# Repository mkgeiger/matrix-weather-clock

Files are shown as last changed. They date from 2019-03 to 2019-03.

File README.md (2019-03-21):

# LED matrix clock with weather informations

## Overview

After my old 7-segmented clock in the living room gave up, I decided to build my own really fancy eye catching clock. The decicion fell on a LED matrix clock (after a Nixie clock was ruled out because of its limited capabilities and relative short tube lifes) because of its 80s retro look. The feature for my needs are:

* the device shall only communicate over WIFI to the outside world
* configurable WIFI access parameters
* the clock shall be using NTP to adjust its time automatically (I am always tired of setting the time after a power failure or when there is a change to the daylight saving time)
* the color of the time shall be configurable and also the seconds to be displayed or not
* a flashing colon (1/s) and a scrolling of the digits (from top to down) for the retro look
* displaying permanently the ouside temperature with a color gradient from blue (cold) to red (hot)
* displaying the actual weather icon and 2 weather forecast icons in the menu row, or alternativly the humidity or the air pressure
* changing the menu by pressing the push button shall have a retro scrolling effect
* the OpenWeatherMap API shall be used for requesting all weather information (I know its sometimes less accurate then commmercial ones, but its free!)
* all individual settings like time zone (incl. daylight saving and nornal time), OpenWeatherMap API key, OpenWeatherMap API city, OpenWeatherMap API units, NTP server address and motion detection hold time shall be configurable with a WEB server providing a settings page.
* a PIR (Pyroelectric Infrared Sensor) shall turn on the display when motion is detected and turn off the display again after a configurable time
* displaying popup notification messages from Android mobile phones

## Mechanics

The different layers
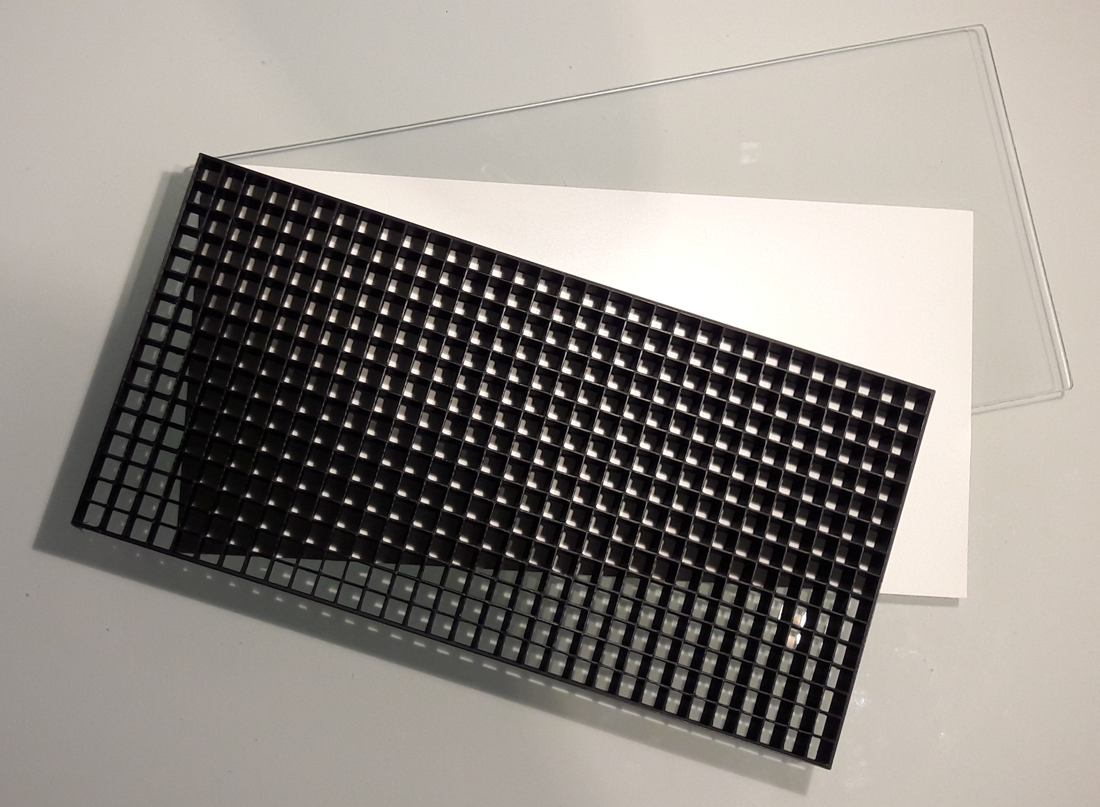
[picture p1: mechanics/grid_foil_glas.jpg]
Layers


### Dividing grid

You need a dividing grid in order to prevent neighbour pixels from blending colors. Without a dividing grid, there will be no sharp edges between two pixels, but a gradient, making the resulting image look blurry. The grid I designed is for a LED matrix display 32x16 RGB P6, means for 6mm led raster. The STL-file (an abbreviation of "stereolithography") created with FreeCad can be downloaded [here](/mechanics/grid.stl). The STL-file can be sent to any online 3D-Print service.

### Diffuser

It is very important to take the thinnest foil but with the most diffused effect at the same time. Don't take diffused acrylic glas, this is too thick and too blury. Plastic sheets from crafting suppliers are also most times too blury. Good results you get with adhesive foils for windows for privacy. I ordered my foils at [Velken](www.velken.de) (item no. 213010 or 213001). Glue instructions from Velken are included.

### Glas pane

Online offers for individual sizes of panes you get at Ebay. A 2mm thick pane is enough. The diffuser foil is glued onto the glas pane. 

## Hardware

### Display

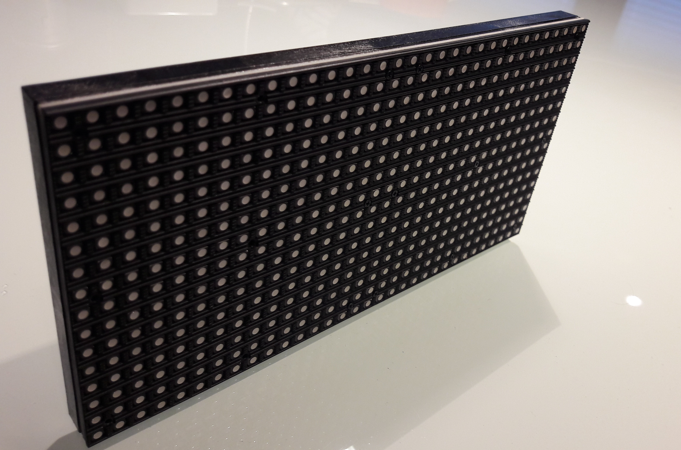
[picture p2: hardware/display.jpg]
Display


This is a LED matrix display which has in total 512 (32x16) RGB LEDs. If you want to learn more about the internal electronic details of such a display, please visit this page: https://bikerglen.com/projects/lighting/led-panel-1up/#The_LED_Panel. The setup and cabling for usage with the PxMatrix driver you should visit the page: https://github.com/2dom/PxMatrix/blob/master/README.md and https://learn.adafruit.com/32x16-32x32-rgb-led-matrix/new-wiring. For powering please visit this page: https://learn.adafruit.com/32x16-32x32-rgb-led-matrix/powering. The main power supply for the display should deliver at least a current of 2A. I had to power the display with about 4.3 Volt, maybe because the logic of display does not detect High-levels (3.3 Volt) from the ESP8266 correctly when powered with 5 Volt.

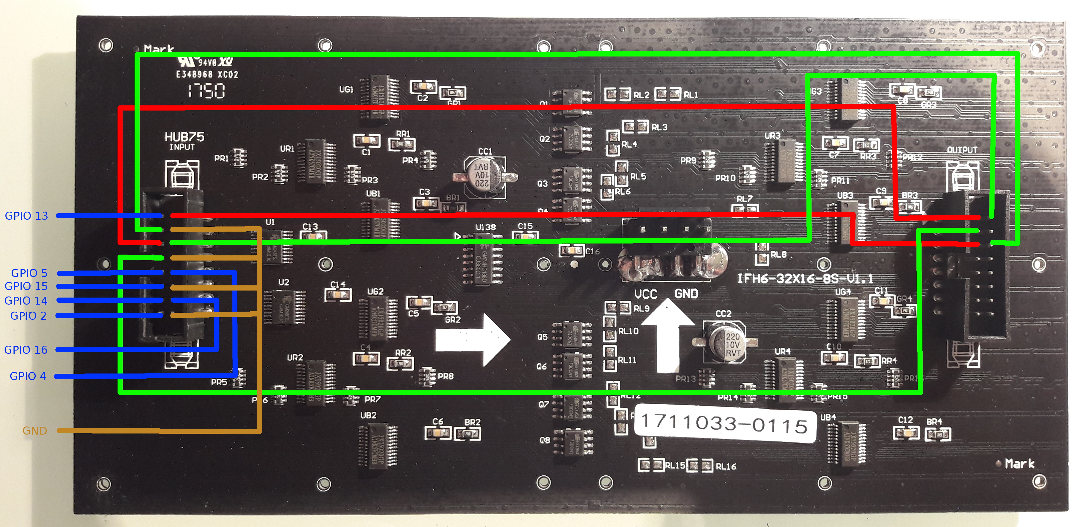
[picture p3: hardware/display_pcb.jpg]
Display


### NodeMcu ESP8266-12E

I decided to take this microcontroller board because of its power, easy programming, WIFI and small form factor. Following GPIOs are used:

  Signal    | ESP8266 | NodeMcu
  ----------|---------|--------
  MOSI (R0) | GPIO13  | D7
  A         | GPIO5   | D1
  B         | GPIO4   | D2
  C         | GPIO15  | D8
  CLK       | GPIO14  | D5
  OE        | GPIO2   | D4
  STB       | GPIO16  | D0
  PIR       | GPIO12  | D6
  BUTTON    | GPIO0   | D3
  GND       | GND     | GND
  
This module can be obtained at Ebay for about 3€.  
  
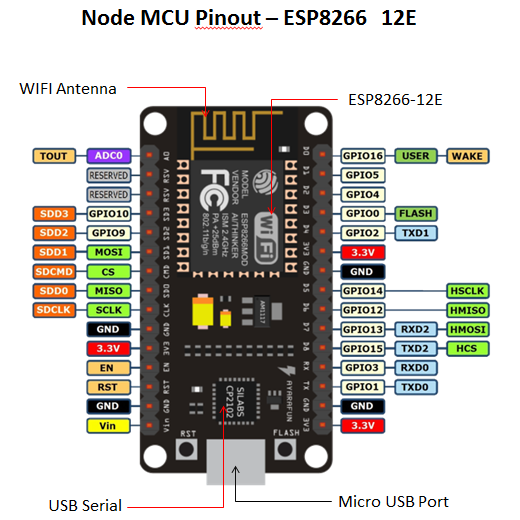
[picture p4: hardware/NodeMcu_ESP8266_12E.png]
NodeMcu
  

### PIR sensor

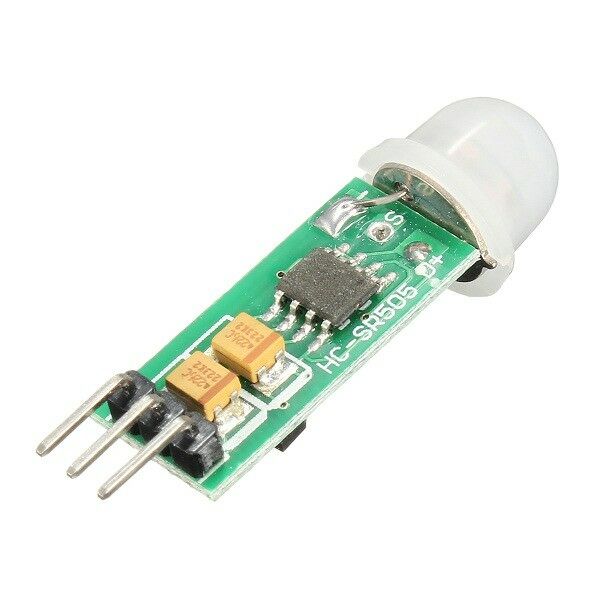
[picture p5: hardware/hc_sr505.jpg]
 

The PIR sensor is used to switch off the display after some configurable time (default 10 min), when no motion is detected. This is mainly for extending the lifetime of the display LEDs. I have choosen the embedded PIR sensor HC-SR505, which is one of the smallest and cheapest. I had to add a suppression choke to filter high frequency signals like WIFI from he power lines, otherwise I got false positives and the display never turned off. The sensing distance for me is also very poor (only 2m) and not 3m as in the datasheet. All in all I have deaktivated the "display switching off" in mean time (DISPLAY_ON_PERMANENTLY), until the problem with the distance is solved. 2 ways to solve: 1. increasing the amplifying factor of the HC-SR505 OPAMP or 2. using the radar sensor [RWCL-0516](/hardware/rwcl_0516.jpg). I tend to solution 2 but no idea of the permanent microwave emission influencing the healt.

## Software

### Preparations

First install the [Arduino IDE](https://www.arduino.cc/en/main/software). Under board administration install support for "NodeMCU 1.0 (ESP-12E Module)". The CPU frequency has to be configured for "160 MHz". Following libraries have to be installed:

* PxMatrix
* Time
* Timezone
* WiFi
* WiFiManager
* DNSServer
* ESP8266WebServer
* ESP8266HTTPClient
* ESP8266mDNS

### NTP client

The NTP client adjusts the internal clock every 10 minutes. The timestamp (UTC Unix time) is converted to the local timezone considering the standard or daylight saving time. An individual NTP server (default: de.pool.ntp.org) can be configured over the WEB interface.

### Time Zone

Timezone

The time zone can be configured over the WEB interface. If the daylight saving time is not applicable to your time zone set both standard and dylight saving times the same values.

### OpenWeatherMap API

* first request an account at [OpenWeatherMap](https://home.openweathermap.org/users/sign_up) to obtain an individual API key.
* test following URLs in your browser and fill in your city and API key: [query1](http://api.openweathermap.org/data/2.5/weather?q=<city>&appid=<apikey>&units=metric) and [query2](http://api.openweathermap.org/data/2.5/forecast?q=<city>&appid=<apikey>&units=metric&cnt=2)
* when you get back the weather information in JSON format, everything is ok. You can now enter the API key, city and unit in the WEB interface.

The [weather condition codes](/datasheets/IconsOpenWeatherMap.pdf) (more detailed than the weather icons) are determined from the JSON response and the corresponding icons (which are designed by myself especially for a matrix display) are displayed. Most icons exist for day and night. A binary search is applied to the icon array when selecting one icon. The [cJSON project](https://github.com/DaveGamble/cJSON) source code is used for parsing the JSON response.

### Motion detection

The status of the PIR sensor is read cyclic. Immediately when a motion is detected the display shows all graphics. The hold time (when no motion is detected anymore) until the display is drawn completely black can be configured in the WEB interface (default: 10 min). Because the range is very poor an alternative would be to use a short range radar for motion detection. Until this is not completely clarified the timeout of the hold time is disabled in the source code to leave the display permanently on.

### HTTP server

The WEB interface is used to store the settings of OpenWeatherMap API, NTP server, time zone and motion detection hold time in the EEPROM. The assigned IP can be found in the router settings. The WIFI settings can be resetted with http://IPaddress/resetWifi. Due to implemented multicast DNS (mDNS) the WEB interface can also be accessed via http://MatrixWeatherClock.local instead of giving the IP. When the "Reset WIFI" button was pressed an access point is started with the following reset (SSID: matrix_weather_clock IP: 192.168.1.1) and new WIFI settings can be configured.

### Android popup notification messages

If desired the user allows Android mobile phones to display popup notification messages like from E-Mail, Whatsapp, Messenger, etc. For this purpose a small App called [LinConnect Client](https://apkpure.com/linconnect-for-linux/com.willhauck.linconnectclient) has to be installed on the Android mobile phone. The LinConnect Client implements the Bonjour-protocol to discover automatically devices in the network offering the (LinConnect-) service. The MatrixWeatherClock acts as a mDNS-responder offering a service for LinLonnect, over which text messages can be transmitted from the client (Android phone) to the server (MatrixWeatherClock). This is done by sending a HTTP PUSH-request, which contains in its HTTP-header the base64-encoded notification-header and -information. The LinConnect Client can be configured which Apps are allowed to send notification messages. The message pops up in the menue line and scrolls from the right to the left.

### Drawing

The display refresh cycle for the [PxMatrix](https://github.com/2dom/PxMatrix) library is configured to 2 ms. The drawing cycle is configured to 100 ms. Within these 100 ms all graphical elements are drawn. A temporary buffer of 1kbyte (32 columns x 16 rows x 2 bytes color) is used as a double buffer, to which every graphical element can draw in its draw cycle. At the end of the draw cycle the complete buffer is copied to the PxMatrix interface to control the LEDs. At the beginning of each draw cycle the buffer is completely cleared. All graphical text elements can be drawn with an individual color. The 100 ms cycle time has been choosen because of the animation effects like colon blinking, digit-, menue- and popup-notification-message scrolling. Menue scrolling is triggered by a push button event.

## Photos

Actual weather icon and weather forecast icons (default view)
(the PIR sensor is visible in the upper left corner, the push button at the upper side of the wooden frame is not visible)

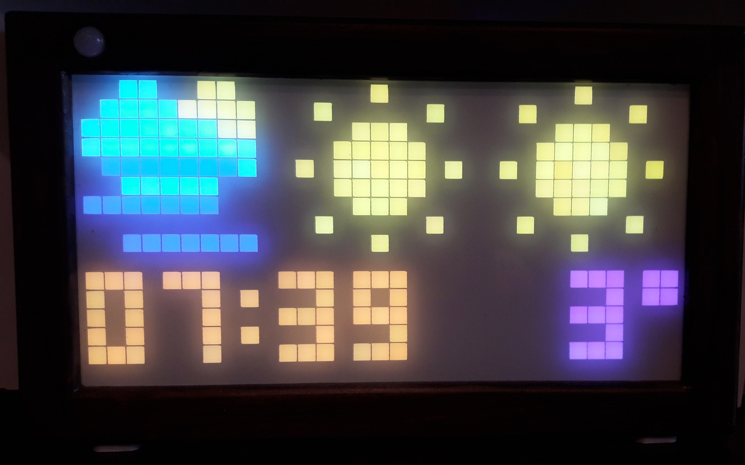
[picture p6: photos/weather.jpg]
Weather


Humidity view (visible after the 1st press of the push button)

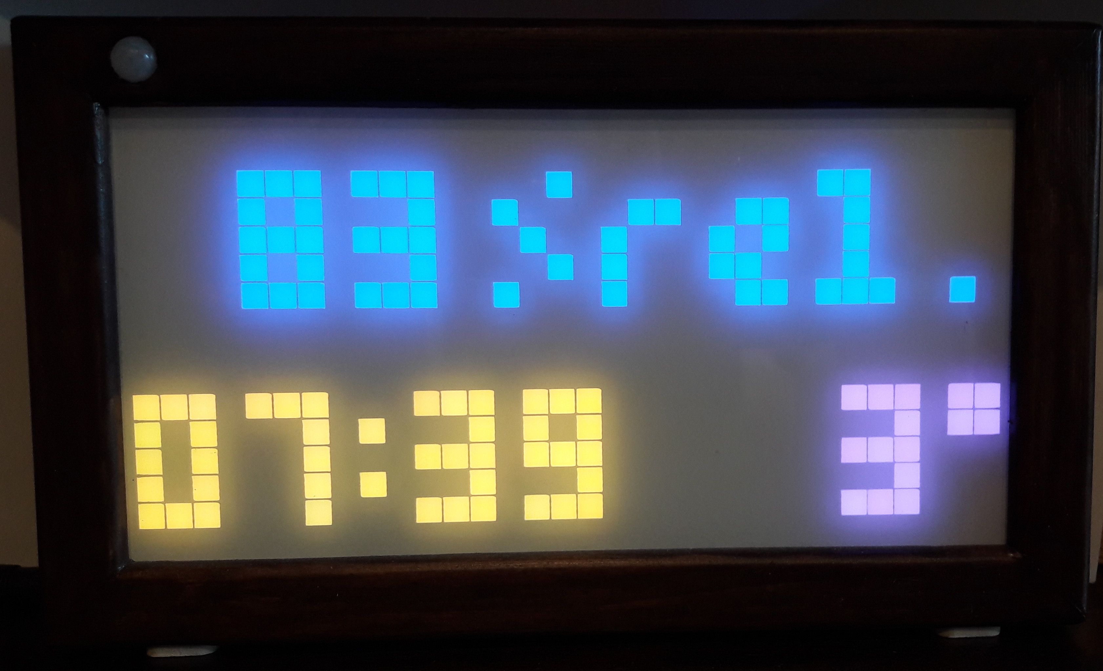
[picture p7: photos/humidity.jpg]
Humidity


Air pressure view (visible after the 2nd press of the push button)

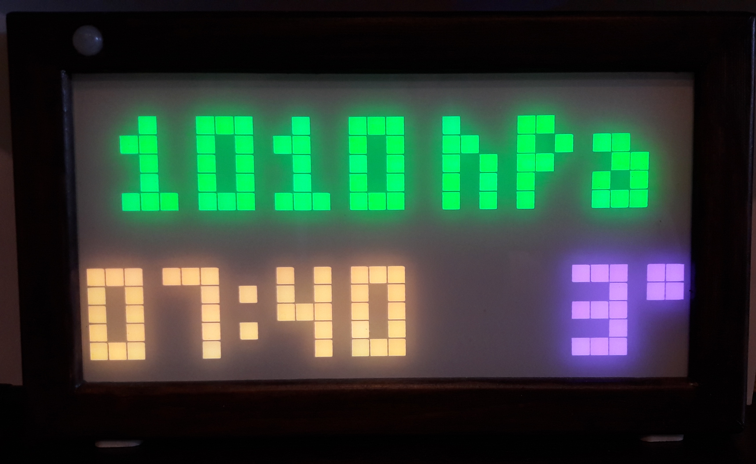
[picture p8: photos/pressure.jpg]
Pressure


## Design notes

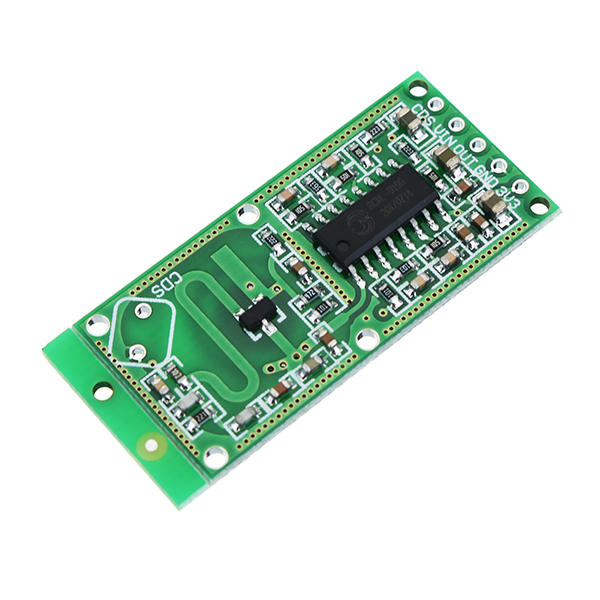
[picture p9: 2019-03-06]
hardware/rwcl_0516.jpg

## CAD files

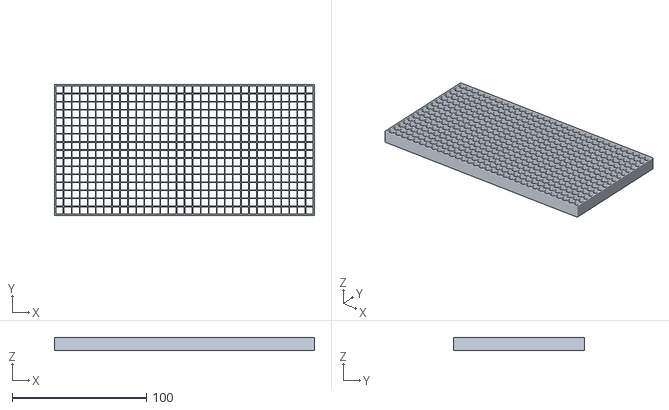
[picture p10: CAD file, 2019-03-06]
mechanics/grid.stl
193.5 x 97.5 x 10.0

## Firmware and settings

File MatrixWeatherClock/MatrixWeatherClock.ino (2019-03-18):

/*=============================================================================
 =======                            INCLUDES                            =======
 =============================================================================*/
#include <PxMatrix.h>
#include <Ticker.h>
#include <TimeLib.h>
#include <Timezone.h> 
#include <ESP8266WiFi.h>
#include <WiFiClient.h>
#include <ESP8266mDNS.h>
#include <DNSServer.h>          // Local DNS Server used for redirecting all requests to the configuration portal
#include <ESP8266WebServer.h>   // Local WebServer used to serve the configuration portal
#include <ESP8266HTTPClient.h>  // HTTPClient for web requests
#include <WiFiManager.h>        // WiFi Configuration Magic
#include <WiFiUdp.h>
#include <EEPROM.h>
#include "base64.h"
#include "cJSON.h"
#include "icons.h"
#include "font.h"

/*=============================================================================
 =======               DEFINES & MACROS FOR GENERAL PURPOSE             =======
 =============================================================================*/
// #define for Uart debugging (printf)
#undef DEBUG

// #undef when PIR range problem is solved
#define DISPLAY_ON_PERMANENTLY

// clock appearance
#undef CLOCK_DISPLAY_SECONDS

// rounding float to integer
#define ROUND_INT(d) ((int) ((d) + ((d) > 0 ? 0.5 : -0.5)))

// access point
#define AP_NAME "matrix_weather_clock"
#define AP_TIMEOUT 300

// general purpose
#define DISPLAY_WIDTH          32
#define DISPLAY_HEIGHT         16
#define NBR_DIGITS             10
#define UPDATE_PERIOD        6000
#define NTP_PACKET_SIZE        48
#define SEVENTYYEARS   2208988800UL
#define PIR_TIME_MAX         6000
#define NBR_MENUS               3
#define LINE0_END               9
#define WEBPAGE_BUFFER_SIZE  3500
#define WEEK_SELECTIONS         5
#define DOW_SELECTIONS          7
#define MONTH_SELECTIONS       12
#define LINE0_TEXT_HOLD_TIME   30   // 3 seconds
#define LINE0_TEXT_BUFSIZE    256

// EEPROM
#define OWM_API_KEY_OFFSET         0
#define OWM_API_KEY_LEN           32
#define OWM_CITY_OFFSET           32
#define OWM_CITY_LEN              32
#define OWM_UNITS_OFFSET          64
#define OWM_UNITS_LEN              8
#define NTP_SERVER_OFFSET         72
#define NTP_SERVER_LEN            32     
#define DT_WEEK_OFFSET           104  
#define DT_WEEK_LEN                1
#define DT_DOW_OFFSET            105
#define DT_DOW_LEN                 1
#define DT_MONTH_OFFSET          106
#define DT_MONTH_LEN               1
#define DT_HOUR_OFFSET           107
#define DT_HOUR_LEN                1
#define DT_OFFSET_OFFSET         108
#define DT_OFFSET_LEN              4
#define ST_WEEK_OFFSET           112  
#define ST_WEEK_LEN                1
#define ST_DOW_OFFSET            113
#define ST_DOW_LEN                 1
#define ST_MONTH_OFFSET          114
#define ST_MONTH_LEN               1
#define ST_HOUR_OFFSET           115
#define ST_HOUR_LEN                1
#define ST_OFFSET_OFFSET         116
#define ST_OFFSET_LEN              4
#define PIR_TIME_OFFSET          120
#define PIR_TIME_LEN               2

// used colors
#define RGB(r, g, b) ((((uint16_t)r & 0x00F8) << 8) | (((uint16_t)g & 0x00FC) << 3) | ((uint16_t)b >> 3))
#define BLK RGB(0, 0, 0)        // Black
#define CYN RGB(127, 255, 255)  // Light Cyan
#define GRY RGB(24, 24, 24)     // Dark Grey
#define YEL RGB(255, 255, 0)    // Yellow
#define BLU RGB(0, 0, 255)      // Blue
#define RED RGB(255, 0, 0)      // Red
#define GRN RGB(0, 255, 0)      // Green
#define ORG RGB(255, 127, 0)    // Orange
#define WHT RGB(255, 255, 255)  // White

// Port Pins for LED Matrix @ ESP8266
#define P_LAT 16
#define P_A    5
#define P_B    4
#define P_C   15
//#define P_D   12
//#define P_E    0
#define P_OE   2

/*=============================================================================
 =======                       CONSTANTS  &  TYPES                      =======
 =============================================================================*/
typedef struct
{
	uint8_t digit_old;
	uint8_t digit_new;
	uint8_t digit_show_old;
	uint8_t digit_show_new;
	uint8_t digit_anim_step;
	uint8_t digit_xoffset;
} digit_anim_t;

const uint16_t color_lut[] = {
		BLK,  // 0
		WHT,  // 1
		YEL,  // 2
		BLU,  // 3
		CYN,  // 4
		GRY,  // 5
		RED   // 6
};

/*=============================================================================
 =======                VARIABLES & MESSAGES & RESSOURCEN               =======
 =============================================================================*/
// timezone: Central European Time (Frankfurt, Paris)
TimeChangeRule daylight_time = { "DT", Last, Sun, Mar, 2, 120 };      //e.g. Central European Summer Time (CEST)
TimeChangeRule standard_time = { "ST", Last, Sun, Oct, 3, 60 };       //e.g. Central European Time (CET)
Timezone time_zone(daylight_time, standard_time);
TimeChangeRule *tcr;                                          //pointer to the time change rule, use to get the TZ abbrev

// Open Weather Map API
String owm_api_key;                                           // Open Weather Map API Key
String owm_city;                                              // Open Weather Map City
String owm_units;                                             // Open Weather Map Units, can be "imperial" or "metric"

// state machine
unsigned char state = 0;
boolean show_valid = false;

// to be displayed values
int temperature   = 9999;
int pressure      = 9999;
int humidity      = 9999;
char daynight_now = 'd';
char daynight_nxt[2] = {'d', 'd'};
int icon_id_now   = 0;
int icon_id_nxt[2] = {0};

// wifi stuff
WiFiManager wifiManager;
WiFiUDP udp;

// time.nist.gov NTP server address, port to listen and packet buffer
IPAddress timeServerIP; 
String ntp_server;          // e.g. de.pool.ntp.org
unsigned int localPort = 2390;
byte packetBuffer[NTP_PACKET_SIZE];

// Set web server port number to 80
ESP8266WebServer server(80);

// Set Linconnect server port number to 9090
WiFiServer linconnect_server(9090);

// matrix display definition, temporary display buffer and icon double buffers
PxMATRIX display(32,16, P_LAT, P_OE, P_A, P_B, P_C);
uint16_t display_buffer[DISPLAY_HEIGHT][DISPLAY_WIDTH] = {{BLK}};
uint8_t icon_buffer[3][2][ICON_HEIGHT * ICON_WIDTH];
uint8_t *icon_buffer_rd[3] = {icon_buffer[0][0], icon_buffer[1][0], icon_buffer[2][0]};
uint8_t *icon_buffer_wr[3] = {icon_buffer[0][1], icon_buffer[1][1], icon_buffer[2][1]};

// timer interrupts
Ticker display_ticker;
Ticker draw_ticker;
uint32_t ms100counter = 0ul;

// PIR
int pir_value = 0;
uint16_t pir_time;
uint16_t pir_count;

// Button
int button_value = 0;
uint8_t button_pressed = 0;

// Menu
uint8_t anim_line0_count = 0;
uint8_t menu = 0;
int16_t line0_xpos = 0;
boolean line0_process = false;
uint8_t line0_pre_showtime = 0;
uint8_t line0_post_showtime = 0;
char b64_decoded[LINE0_TEXT_BUFSIZE];

// Webpage
char webpage_buffer[WEBPAGE_BUFFER_SIZE];
String dt_week_selected[WEEK_SELECTIONS] = {"", "", "", "", ""};
String dt_dow_selected[DOW_SELECTIONS] = {"", "", "", "", "", "", ""};
String dt_month_selected[MONTH_SELECTIONS] = {"", "", "", "", "", "", "", "", "", "", "", ""};
String st_week_selected[WEEK_SELECTIONS] = {"", "", "", "", ""};
String st_dow_selected[DOW_SELECTIONS] = {"", "", "", "", "", "", ""};
String st_month_selected[MONTH_SELECTIONS] = {"", "", "", "", "", "", "", "", "", "", "", ""};
uint8_t dt_hour;
int     dt_offset;
uint8_t st_hour;
int     st_offset;

/*=============================================================================
 =======                              METHODS                           =======
 =============================================================================*/
const uint8_t * getIcon(char daynight, int icon_number)
{
	int left, middle, right, icon_nr;

	left = 0;
	right = NBR_ICONS - 1;

	while (left <= right)
	{
		middle = (left + right) / 2;

		icon_nr = (int)pgm_read_dword (&icon_list[middle].icon_number);

		if (icon_number > icon_nr)
		{
			left = middle + 1;
		}

		if (icon_number < icon_nr)
		{
			right = middle - 1;
		}

		if(icon_number == icon_nr)
		{
			if (daynight == 'd')
			{
				return (const uint8_t *)pgm_read_dword (&icon_list[middle].icon_day);
			}
			else
			{
				return (const uint8_t *)pgm_read_dword (&icon_list[middle].icon_night);
			}
		}
	}
	return NULL;
}

void draw_digit(uint8_t x_pos, uint8_t y_pos, uint8_t d, uint16_t color)
{
	uint8_t x, y;

	for (y = 1; y < (FONT_HEIGHT - 1); y ++)
	{
		for (x = 0; x < FONT_WIDTH; x ++)
		{
			display_buffer[y_pos + y - 1][x_pos + x] = color_lut[charactermap['0' + d][y][x]] & color;
		}
	}  
}

void draw_character(int16_t x_pos, int16_t y_pos, char c, uint16_t color)
{
	int16_t x, y;

	if ((x_pos > -3) && (x_pos < DISPLAY_WIDTH))
	{
		for (x = 0; x < FONT_WIDTH; x ++)
		{
			if ((y_pos > -3) && (y_pos < DISPLAY_HEIGHT))
			{
				for (y = 1; y < FONT_HEIGHT; y ++)
				{
					if (((x_pos + x) >= 0) && ((x_pos + x) < DISPLAY_WIDTH))
					{
						display_buffer[y_pos + y - 1][x_pos + x] = color_lut[charactermap[c][y][x]] & color;
					}
				}
			}
		}
	}
}

void draw_character_ext(int16_t x_pos, int16_t y_pos, const uint8_t character[][FONT_WIDTH], uint16_t color)
{
	int16_t x, y;

	if ((x_pos > -3) && (x_pos < DISPLAY_WIDTH))
	{
		for (x = 0; x < FONT_WIDTH; x ++)
		{
			if ((y_pos > -3) && (y_pos < DISPLAY_HEIGHT))
			{
				for (y = 1; y < FONT_HEIGHT; y ++)
				{
					if (((x_pos + x) >= 0) && ((x_pos + x) < DISPLAY_WIDTH))
					{
						display_buffer[y_pos + y - 1][x_pos + x] = color_lut[character[y][x]] & color;
					}
				}
			}
		}
	}
}

void utf8_draw_string(int16_t x_pos, int16_t y_pos, char *str, uint16_t color)
{
	int c[4];
	int i, len = 0;
	unsigned long code;

	for (i = 0; i < strlen(str); i ++)
	{
		c[0] = (unsigned char)str[i];
		if ((c[0] >= 0) && (c[0] <= 127))
		{
			draw_character (x_pos + len * (FONT_WIDTH + 1), y_pos, (char)c[0], color);
		}
		else if ((c[0] & 0xE0) == 0xC0)
		{
			c[1] = (unsigned char)str[i + 1];
			code = (((unsigned long)c[0]) << 8) | ((unsigned long)c[1]);
			switch(code)
			{
			case 0xC2A3:
				draw_character_ext(x_pos + len * (FONT_WIDTH + 1), y_pos, char_0xC2A3, color);
				break;
			case 0xC2A7:
				draw_character_ext(x_pos + len * (FONT_WIDTH + 1), y_pos, char_0xC2A7, color);
				break;
			case 0xC2A9:
				draw_character_ext(x_pos + len * (FONT_WIDTH + 1), y_pos, char_0xC2A9, color);
				break;
			case 0xC2AB:
				draw_character_ext(x_pos + len * (FONT_WIDTH + 1), y_pos, char_0xC2AB, color);
				break;
			case 0xC2B0:
				draw_character_ext(x_pos + len * (FONT_WIDTH + 1), y_pos, char_0xC2B0, color);
				break;
			case 0xC2B1:
				draw_character_ext(x_pos + len * (FONT_WIDTH + 1), y_pos, char_0xC2B1, color);
				break;
			case 0xC2B2:
				draw_character_ext(x_pos + len * (FONT_WIDTH + 1), y_pos, char_0xC2B2, color);
				break;
			case 0xC2B3:
				draw_character_ext(x_pos + len * (FONT_WIDTH + 1), y_pos, char_0xC2B3, color);
				break;
			case 0xC2B4:
				draw_character_ext(x_pos + len * (FONT_WIDTH + 1), y_pos, char_0xC2B4, color);
				break;
			case 0xC2B5:
				draw_character_ext(x_pos + len * (FONT_WIDTH + 1), y_pos, char_0xC2B5, color);
				break;
			case 0xC2BB:
				draw_character_ext(x_pos + len * (FONT_WIDTH + 1), y_pos, char_0xC2BB, color);
				break;
			case 0xC384:
				draw_character_ext(x_pos + len * (FONT_WIDTH + 1), y_pos, char_0xC384, color);
				break;
			case 0xC396:
				draw_character_ext(x_pos + len * (FONT_WIDTH + 1), y_pos, char_0xC396, color);
				break;
			case 0xC397:
				draw_character_ext(x_pos + len * (FONT_WIDTH + 1), y_pos, char_0xC397, color);
				break;
			case 0xC39C:
				draw_character_ext(x_pos + len * (FONT_WIDTH + 1), y_pos, char_0xC39C, color);
				break;
			case 0xC39F:
				draw_character_ext(x_pos + len * (FONT_WIDTH + 1), y_pos, char_0xC39F, color);
				break;
			case 0xC3A4:
				draw_character_ext(x_pos + len * (FONT_WIDTH + 1), y_pos, char_0xC3A4, color);
				break;
			case 0xC3B6:
				draw_character_ext(x_pos + len * (FONT_WIDTH + 1), y_pos, char_0xC3B6, color);
				break;
			case 0xC3B7:
				draw_character_ext(x_pos + len * (FONT_WIDTH + 1), y_pos, char_0xC3B7, color);
				break;
			case 0xC3BC:
				draw_character_ext(x_pos + len * (FONT_WIDTH + 1), y_pos, char_0xC3BC, color);
				break;
			default:
				draw_character_ext(x_pos + len * (FONT_WIDTH + 1), y_pos, char_unknown, color);
				break;
			}
			i += 1;
		}
		else if ((c[0] & 0xF0) == 0xE0)
		{
			c[1] = (unsigned char)str[i + 1];
			c[2] = (unsigned char)str[i + 2];
			code = (((unsigned long)c[0]) << 16) | (((unsigned long)c[1]) << 8) | ((unsigned long)c[2]);
			switch(code)
			{
			case 0xE2809C:
				draw_character_ext(x_pos + len * (FONT_WIDTH + 1), y_pos, char_0xE2809C, color);
				break;
			case 0xE2809E:
				draw_character_ext(x_pos + len * (FONT_WIDTH + 1), y_pos, char_0xE2809E, color);
				break;
			case 0xE282AC:
				draw_character_ext(x_pos + len * (FONT_WIDTH + 1), y_pos, char_0xE282AC, color);
				break;
			default:
				draw_character_ext(x_pos + len * (FONT_WIDTH + 1), y_pos, char_unknown, color);
				break;
			}
			i += 2;
		}
		else if ((c[0] & 0xF8) == 0xF0)
		{
			c[1] = (unsigned char)str[i + 1];
			c[2] = (unsigned char)str[i + 2];
			c[3] = (unsigned char)str[i + 3];
			code = (((unsigned long)c[0]) << 24) | (((unsigned long)c[1]) << 16) | (((unsigned long)c[2]) << 8) | ((unsigned long)c[3]);

			if (((code >= 0xf09f9880) && (code <= 0xf09f988f)) ||
					((code >= 0xf09f9897) && (code <= 0xf09f989d)) ||
					((code >= 0xf09f9982) && (code <= 0xf09f9983)))
			{
				draw_character_ext(x_pos + len * (FONT_WIDTH + 1), y_pos, char_smile, WHT);
			}
			else if (((code >= 0xf09f9890) && (code <= 0xf09f9891)) ||
					((code >= 0xf09f98b6) && (code <= 0xf09f98b7)) ||
					(code == 0xf09f9984))
			{
				draw_character_ext(x_pos + len * (FONT_WIDTH + 1), y_pos, char_neutral, WHT);
			}
			else if (((code >= 0xf09f9892) && (code <= 0xf09f9896)) ||
					((code >= 0xf09f989e) && (code <= 0xf09f98b5)) ||
					(code == 0xf09f9981))
			{
				draw_character_ext(x_pos + len * (FONT_WIDTH + 1), y_pos, char_frown, WHT);
			}
			else
			{
				draw_character_ext(x_pos + len * (FONT_WIDTH + 1), y_pos, char_unknown, color);
			}
			i += 3;
		}
		else return;  //invalid utf8

		len ++;
	}
}

int utf8_strlen(char *str)
{
	int c;
	int i, len = 0;

	for (i = 0; i < strlen(str); i ++)
	{
		c = (unsigned char)str[i];
		if      ((c >= 0) && (c <= 127)) i += 0;
		else if ((c & 0xE0) == 0xC0)     i += 1;
		else if ((c & 0xF0) == 0xE0)     i += 2;
		else if ((c & 0xF8) == 0xF0)     i += 3;
		else return 0;  //invalid utf8
		len ++;
	}
	return len;
}

boolean draw_news_line0(int16_t y_pos, char *str, uint16_t color)
{
	uint8_t x, y;

	if (line0_pre_showtime < LINE0_TEXT_HOLD_TIME)
	{
		line0_pre_showtime ++;
	}

	utf8_draw_string(line0_xpos, y_pos, str, color);	
	if ((line0_xpos == (1 - ((utf8_strlen(str) - DISPLAY_WIDTH / (FONT_WIDTH + 1)) * (FONT_WIDTH + 1)))) ||
			(utf8_strlen(str) <= (DISPLAY_WIDTH / (FONT_WIDTH + 1))))
	{
		if (line0_post_showtime < LINE0_TEXT_HOLD_TIME)
		{
			line0_post_showtime ++;
		}

		if (line0_post_showtime == LINE0_TEXT_HOLD_TIME)
		{
			line0_pre_showtime = 0;
			line0_post_showtime = 0;
			line0_xpos = 0;
			return false;
		}
		else
		{
			return true;
		}
	}
	else
	{
		if (line0_pre_showtime == LINE0_TEXT_HOLD_TIME)
		{
			line0_xpos --;
		}
		return true;
	}
}

// anim_step = 1, 2, 3, 4, 5, 6
void draw_digit_anim(uint8_t x_pos, uint8_t y_pos, uint8_t d_old, uint8_t d_new, uint8_t anim_step, uint16_t color)
{
	uint8_t x, y;

	for (y = 1; y < anim_step; y ++)
	{
		for (x = 0; x < FONT_WIDTH; x ++)
		{
			display_buffer[y_pos + y - 1][x_pos + x] = color_lut[charactermap['0' + d_new][FONT_HEIGHT - 1 - anim_step + y][x]] & color;
		}
	}  
	for (y = anim_step; y < (FONT_HEIGHT - 1); y ++)
	{
		for (x = 0; x < FONT_WIDTH; x ++)
		{
			display_buffer[y_pos + y - 1][x_pos + x] = color_lut[charactermap['0' + d_old][y - anim_step][x]] & color;
		}
	}  
}

void draw_weather_icon (int buf_nbr, uint8_t x_pos, uint8_t y_pos)
{
	uint8_t x, y;

	for (y = 0; y < ICON_HEIGHT; y ++)
	{
		for (x = 0; x < ICON_WIDTH; x ++)
		{
			display_buffer[y_pos + y][x_pos + x] = color_lut[icon_buffer_rd[buf_nbr][y * ICON_WIDTH + x]];
		}
	} 
}

void draw_weather_icon_dbuffer (int buf_nbr, char daynight, int icon_id)
{
	uint8_t *ptr;
	const uint8_t *icon = getIcon(daynight, icon_id);
	if (icon != NULL)
	{
		memcpy_P(icon_buffer_wr[buf_nbr], icon, ICON_HEIGHT * ICON_WIDTH);

		// toggle double buffer
		ptr = icon_buffer_rd[buf_nbr];
		icon_buffer_rd[buf_nbr] = icon_buffer_wr[buf_nbr];
		icon_buffer_wr[buf_nbr] = icon_buffer_rd[buf_nbr];
	}
}
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
void loop() 
{ 
	if (WiFi.status() == WL_CONNECTED)
	{
		MDNS.update();                 // Processing mDNS

		server.handleClient();         // Handling of incoming requests
	}

	pir_value = digitalRead(D6);
	if (pir_value != 0)
	{
		pir_count = pir_time * 10;
	}

	button_value = digitalRead(D3);
	if (button_value != 0)
	{
		button_pressed = 0;
	}
	else
	{
		button_pressed = 1;
	}

	switch (state)
	{
	case 0:     
		if (WiFi.status() == WL_CONNECTED)
		{
			WiFi.hostByName(ntp_server.c_str(), timeServerIP);
			sendNTPpacket(timeServerIP); // send an NTP packet to a time server
			ms100counter = 0;
			state = 1;
		}
		break;
	case 1:
		if (ms100counter >= 10) // wait at least 1 sec for ntp response
		{
			ms100counter = 0;
			state = 2;
		}
		break;
	case 2:
		if (WiFi.status() == WL_CONNECTED)
		{
			if (NTP_PACKET_SIZE <= udp.parsePacket())
			{
				unsigned long secsSince1900;
				unsigned long epoch;

				// We've received a packet, read the data from it
				udp.read(packetBuffer, NTP_PACKET_SIZE);

				//the timestamp starts at byte 40 of the received packet and is four bytes,
				secsSince1900  = (unsigned long)packetBuffer[40] << 24;
				secsSince1900 |= (unsigned long)packetBuffer[41] << 16;
				secsSince1900 |= (unsigned long)packetBuffer[42] << 8;
				secsSince1900 |= (unsigned long)packetBuffer[43];

				// now convert NTP time into everyday time.
				// Unix time starts on Jan 1 1970. In seconds, that's 2208988800.
				// subtract seventy years.
				epoch = secsSince1900 - SEVENTYYEARS;
				setTime(epoch);

#ifdef DEBUG
				// print Unix time
				Serial.print("Unix time = ");
				Serial.println(epoch);
#endif
			}
			ms100counter = 0;
			state = 3;
		}
		else
		{
			state = 0;
		}
		break; 
	case 3:
		if (ms100counter >= 50)  // wait 5 seconds
		{
			ms100counter = 0;
			state = 4;
		}
		break;
	case 4:
		if (WiFi.status() == WL_CONNECTED)
		{
			getCurrentWeather();
		}
		ms100counter = 0;
		state = 5;
		break;
	case 5:
		if (ms100counter >= 50) // wait 5 seconds
		{
			ms100counter = 0;
			state = 6;
		}
		break;
	case 6:
		if (WiFi.status() == WL_CONNECTED)
		{
			getForecastWeather();
		}
		ms100counter = 0;
		state = 7;
		show_valid = true;
		break;
	case 7:
		if (ms100counter >= UPDATE_PERIOD) // wait 10 minutes
		{
			ms100counter = 0;
			state = 0;
		}
		break;
	default:
		break;
	}

	if (WiFi.status() == WL_CONNECTED)
	{
		if (line0_process == false)
		{
			// Wait for a linconnect client to connect
			WiFiClient linconnect_client = linconnect_server.available();
			if (linconnect_client)
			{
				int len;

				while (linconnect_client.connected())
				{
					// Read line by line what the client is requesting
					if (linconnect_client.available())
					{
						String line = linconnect_client.readStringUntil('\r');
						if (line.substring(1, 13) == "notifheader:")
						{
							len = b64_decode( b64_decoded , sizeof(b64_decoded), (char *)line.substring(14).c_str() , line.substring(14).length() );
							if (len < (sizeof(b64_decoded)	- 2))
							{
								b64_decoded[len++] = ':';
								b64_decoded[len++] = ' ';
								b64_decoded[len] = 0;
							}
						}
						if (line.substring(1, 18) == "notifdescription:")
						{
							if ((sizeof(b64_decoded) - len) > 1)
							{
								b64_decode( &b64_decoded[len] , sizeof(b64_decoded) - len, (char *)line.substring(19).c_str() , line.substring(19).length() );
							}
						}

						// Wait for end of client's request, that is marked with an empty line
						if (line.length() == 1 && line[0] == '\n')
						{
							linconnect_client.println(String("HTTP/1.1 200 OK\r\n") + "Content-Length: 4\r\n" + "Content-Type: text/html;charset=utf-8\r\n\r\n" + "true");
							line0_process = true;
							break;
						}
					}
				}
				// Give the client time to receive the data
				delay(1);

				// close the connection:
				linconnect_client.stop();
			}
		}
	}

	yield();
}

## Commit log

2019-03-06 Add files via upload
    wires added
2019-03-06 Update README.md
    PIR sensor description added
